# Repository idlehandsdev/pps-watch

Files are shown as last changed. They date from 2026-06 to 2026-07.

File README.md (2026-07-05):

# PPS Watch  

### The Most Accurate Watch that Doesn't Tell Time.

Watch the video (https://youtu.be/AHSqyuOPpf0)

---

## What it does

- Receives GPS , achieves position/time fix
- Outputs 1PPS (one pulse per second) on the GPS module's hardware TIMEPULSE pin, silent until locked, active at 1Hz once locked
- Distributes that PPS signal across a BNC connector via buffered outputs
- Accepts an external PPS reference, compares it against the GPS PPS via a hardware XOR phase comparator, with LED indicators for PPS presence and phase offset
- No microcontroller. No firmware. The GPS module's hardware PPS pin drives the LEDs and BNC outputs directly through logic buffers.

## Hardware

- **GPS module:** u-blox MAX-M10S
- **Antenna:** External via SMA, no onboard antenna. Direct-mount stub antennas (Quectel YEGT001AA right-angle / YEGT002AA straight) screw directly onto the SMA connector, no cable
- **Buffering:** 2x 74HC125 quad buffer (GPS output side, external input side)
- **Comparator:** 74AHC1G86 single XOR gate
- **Indicators:** 0805 SMD LEDs -- 1x red (PPS), 2x green (fix / external PPS)
- **Power:** CR2450 coin cell, switched via SW1, V_BCKP always connected
- **Config port:** Qwiic (I2C) for one-time setup via u-center if needed
- **Connectors:** 2x BNC, 1x SMA (antenna), 1x Qwiic

See the schematic for full signal flow and the BOM for part numbers.

## CAD

This is a KiCad project. PCB mechanical design and 3D assembly were done in Fusion 360.

**Fusion 360 share link:** https://a360.co/4xXmWnG

## BOM

- ** BOM should be up to date! - https://www.digikey.ca/en/mylists/list/XIH163JVIJ
- ** R2 was a 0R resistor, but the BOM now includes a PTC instead.

| Reference | Qty | Value | Digikey Part No. |
|---|---|---|---|
| AE3 | 1 | YEGT002AA | [2958-YEGT002AA-ND](https://www.digikey.com/en/products/detail/quectel/YEGT002AA/17101891) |
| BT2 | 1 | BU2450SM-JJ-G | [BU2450SM-JJ-GCT-ND](https://www.digikey.com/en/products/detail/mpd-memory-protection-devices/BU2450SM-JJ-GTR/3028728) |
| C1 | 1 | 100pF C0G | 311-1111-1-ND |
| C2, C3, C4, C5 | 4 | 0.1uF | 311-4348-1-ND |
| D1 | 1 | LED Red 0805 | 160-1415-1-ND |
| D2 | 1 | PESD0402-140 | [PESD0402-140CT-ND](https://www.digikey.com/en/products/detail/littelfuse-inc/PESD0402-140/1968526) |
| D3, D4 | 2 | LED Green 0805 | [475-LGR971-KN-1TR-ND](https://www.digikey.com/en/products/detail/LG%20R971-KN-1/475-1410-1-ND/1802598) |
| J1, J4 | 2 | BNC 2466267-1 | 17-2466267-1-ND |
| J2 | 1 | CONSMA002-SMD-G-T | 343-CONSMA002-SMD-G-TCT-ND |
| J6 | 1 | Qwiic | 1568-14417-ND |
| L1 | 1 | Ferrite Bead | 490-1040-1-ND |
| R1 | 1 | 470R | 311-470ARCT-ND |
| R2 | 1 | 500mA PolyFuse | F2772CT-ND |
| R3, R6 | 2 | 10K | 311-10KARCT-ND |
| R4, R5 | 2 | 330R | 311-330ARCT-ND |
| SW1 | 1 | Power Switch SPDT | 401-2016-1-ND |
| U1 | 1 | MAX-M10S | 672-MAX-M10S-00BTR-ND |
| U3, U6 | 2 | 74HC125D | [74HC125DCT-ND](https://www.digikey.com/en/products/detail/toshiba-semiconductor-and-storage/74HC125D/6198795) |
| U5 | 1 | 74AHC1G86 | [296-1094-1-ND](https://www.digikey.com/en/products/detail/texas-instruments/SN74AHC1G86DBVR/276738) |

## Watch Assembly

### 3D Printed Parts

Print the following files from the `CAD/` folder:

- `CAD/pcb_frame_mount.stl` -- frame that holds the PCB
- `CAD/watch_band_mount.stl` -- mounts the band to the frame

### Watch Band

Any standard 22mm watch band works. Tested with:

[Bandini Nylon Sports Watch Band Strap 22mm](https://www.amazon.com/dp/B09R2BVRWQ)

### Hardware

- 2 x M2x6mm Flat Head Plastic Threading Screws to mount body to strap mount. - https://www.mcmaster.com/90485A415/
- 2 x M3x6mm Pan Head Plastic Threading Screws for mounting PCB to Body - https://www.mcmaster.com/99461A939/
- 2 x M3x35mm Round Head Machine Screws to mount strap. Just Thread into the plastic snugly https://www.mcmaster.com/92000A134/
---

*Felix Corp -- Idle Hands Dev R&D Division*
*Asset Tag: FC-IDH-UTC-001*

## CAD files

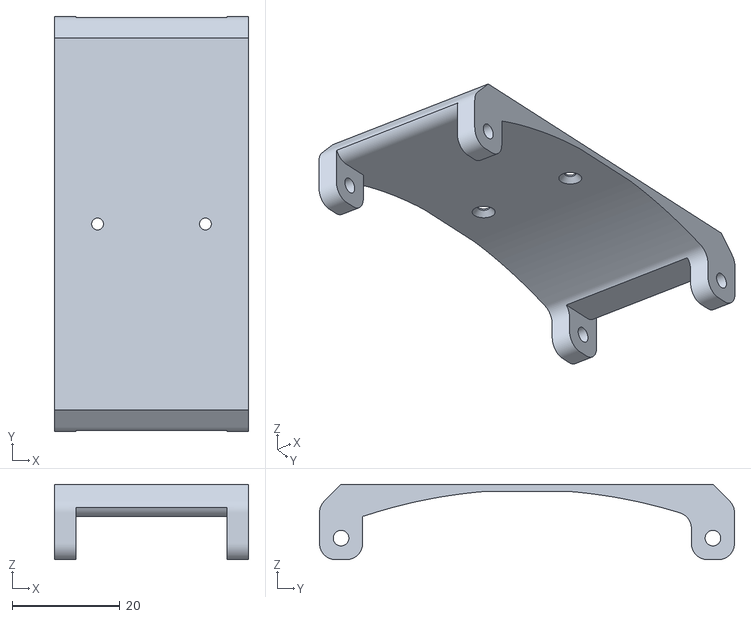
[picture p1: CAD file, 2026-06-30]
CAD/watch_band_mount.stl
36.0 x 77.0 x 14.0

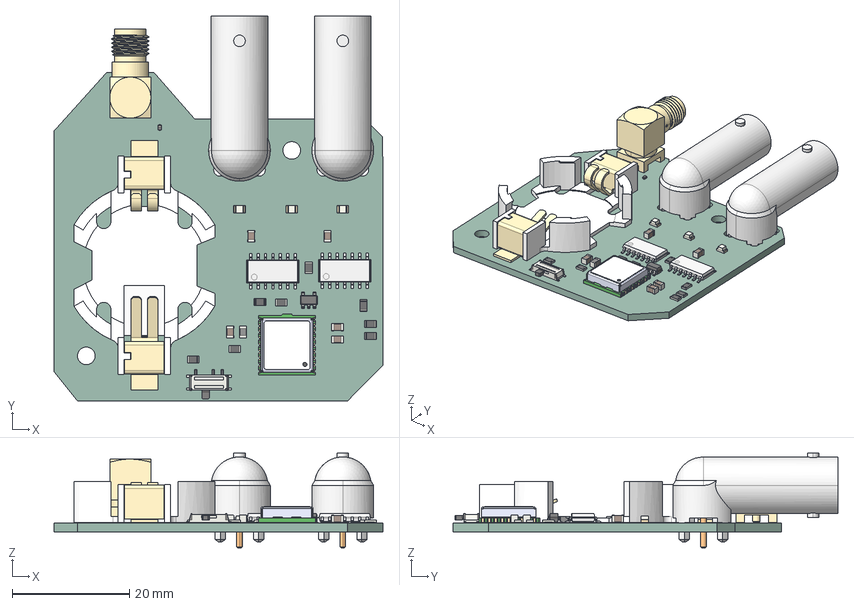
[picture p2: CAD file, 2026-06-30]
kicad/pps_watch.step
56.0 x 65.6 x 16.2 mm
R_0805_2012Metric x 8
BU2450SM-JJ-G
SOT-23-5
Fusion_sp
LED_0805_2012Metric x 3
C_0805_2012Metric x 5
MAX-M10S-00B
CONSMA002-SMD-G
D_SOD_923
L_0805_2012Metric
pps_watch_PCB

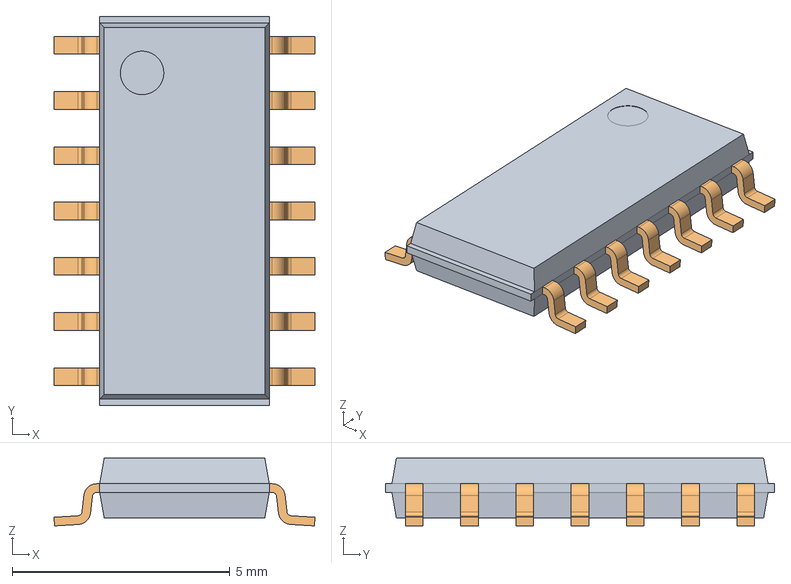
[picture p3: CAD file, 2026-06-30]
kicad/project_libs/3DPackages/SOIC14_z90.stp
6.00 x 8.95 x 1.56 mm

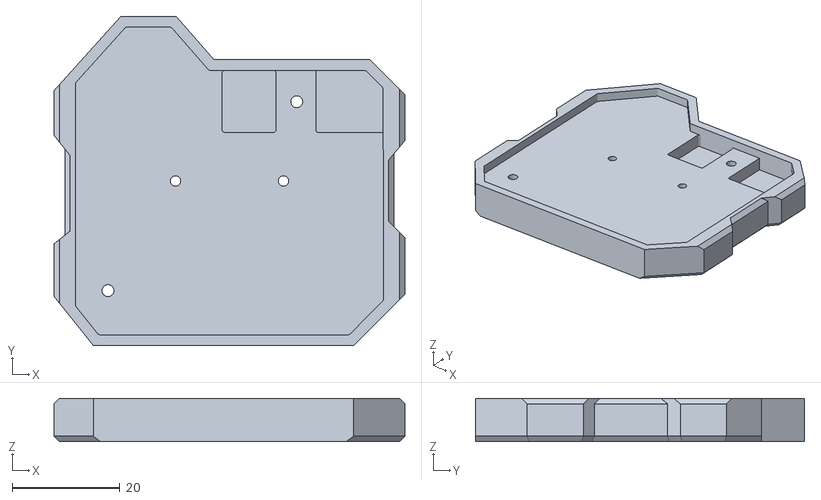
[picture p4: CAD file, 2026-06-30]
CAD/pcb_frame_mount.stl
65.0 x 61.0 x 8.00

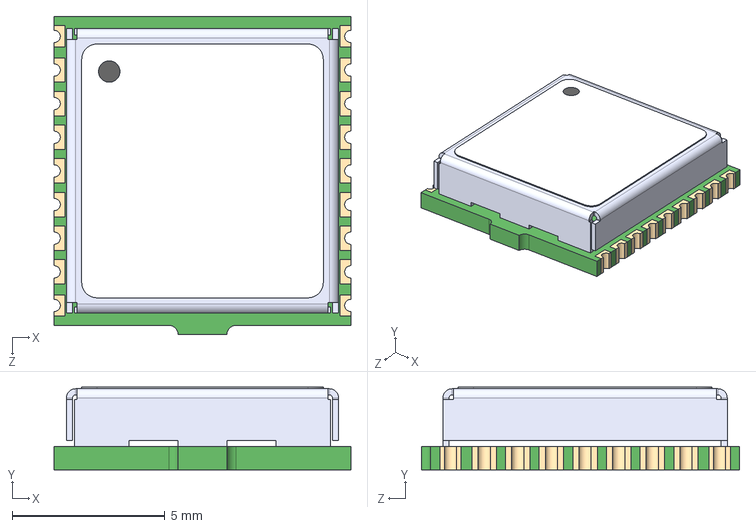
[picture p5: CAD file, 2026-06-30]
kicad/project_libs/3DPackages/MAX-M10S-00B.step
9.70 x 2.70 x 10.4 mm

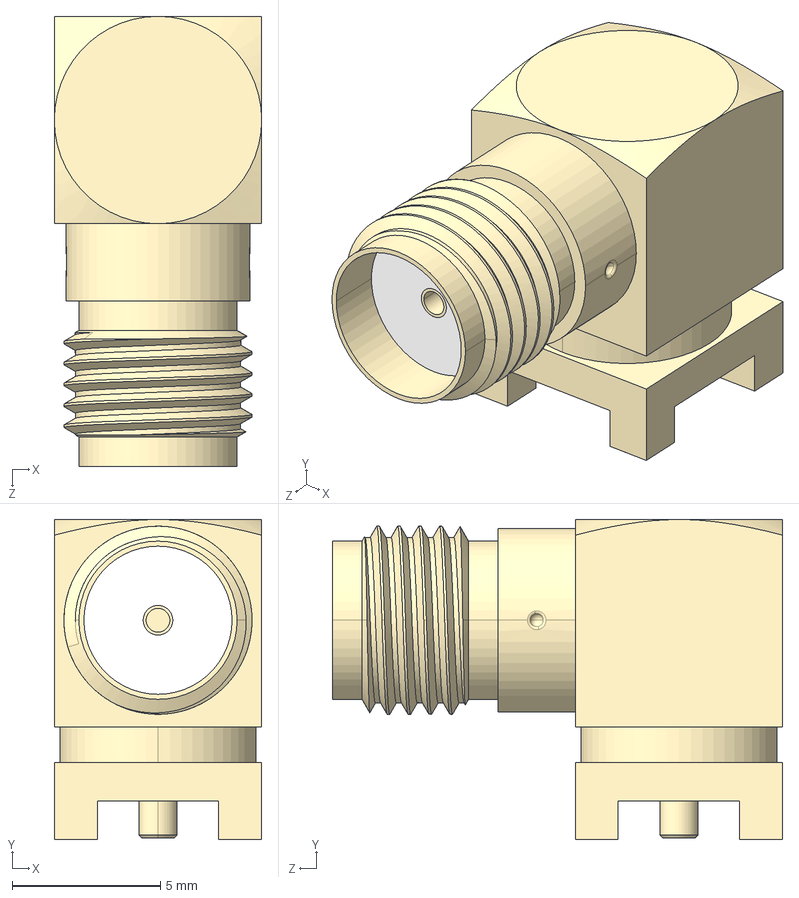
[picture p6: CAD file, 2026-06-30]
kicad/project_libs/3DPackages/CONSMA002-SMD-G-T.step
7.00 x 10.8 x 15.2 mm

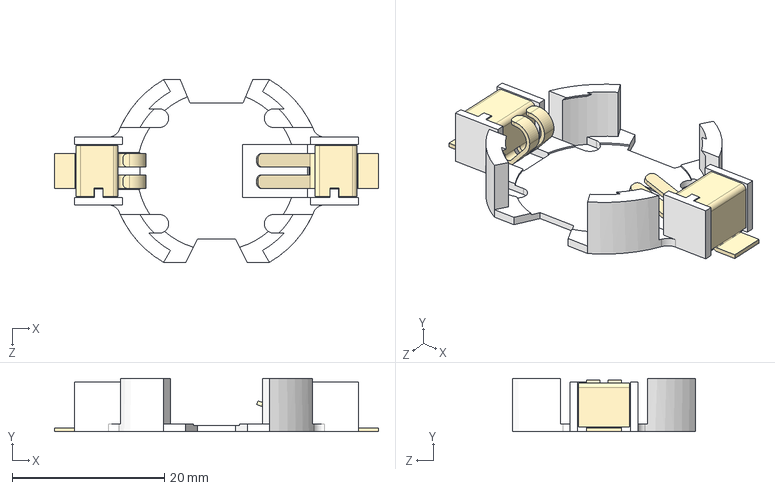
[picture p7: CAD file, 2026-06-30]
kicad/project_libs/3DPackages/BU2450SM-JJ-G.step
42.5 x 7.00 x 24.0 mm

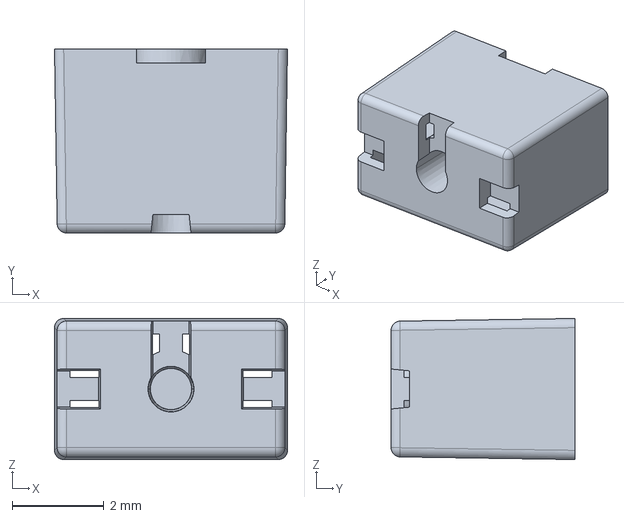
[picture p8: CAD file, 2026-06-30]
kicad/project_libs/3DPackages/1462350001.stp
5.07 x 4.00 x 3.07 mm

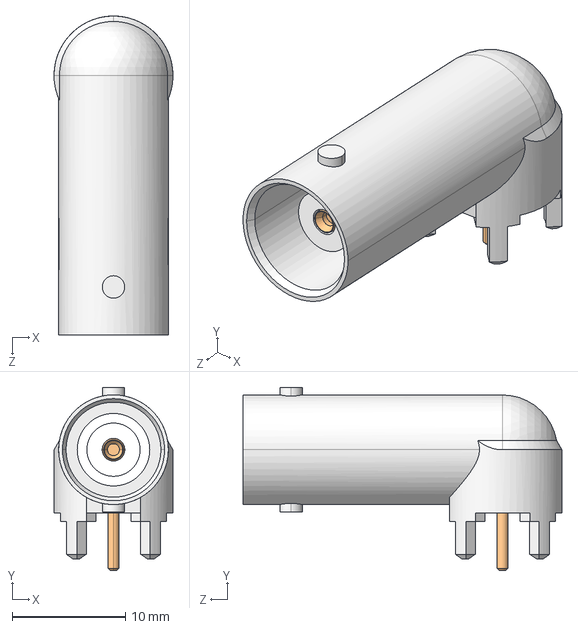
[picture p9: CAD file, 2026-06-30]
kicad/project_libs/3DPackages/2466267-1.step
10.5 x 16.2 x 28.1 mm

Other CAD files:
CAD/watch_frame.f3d

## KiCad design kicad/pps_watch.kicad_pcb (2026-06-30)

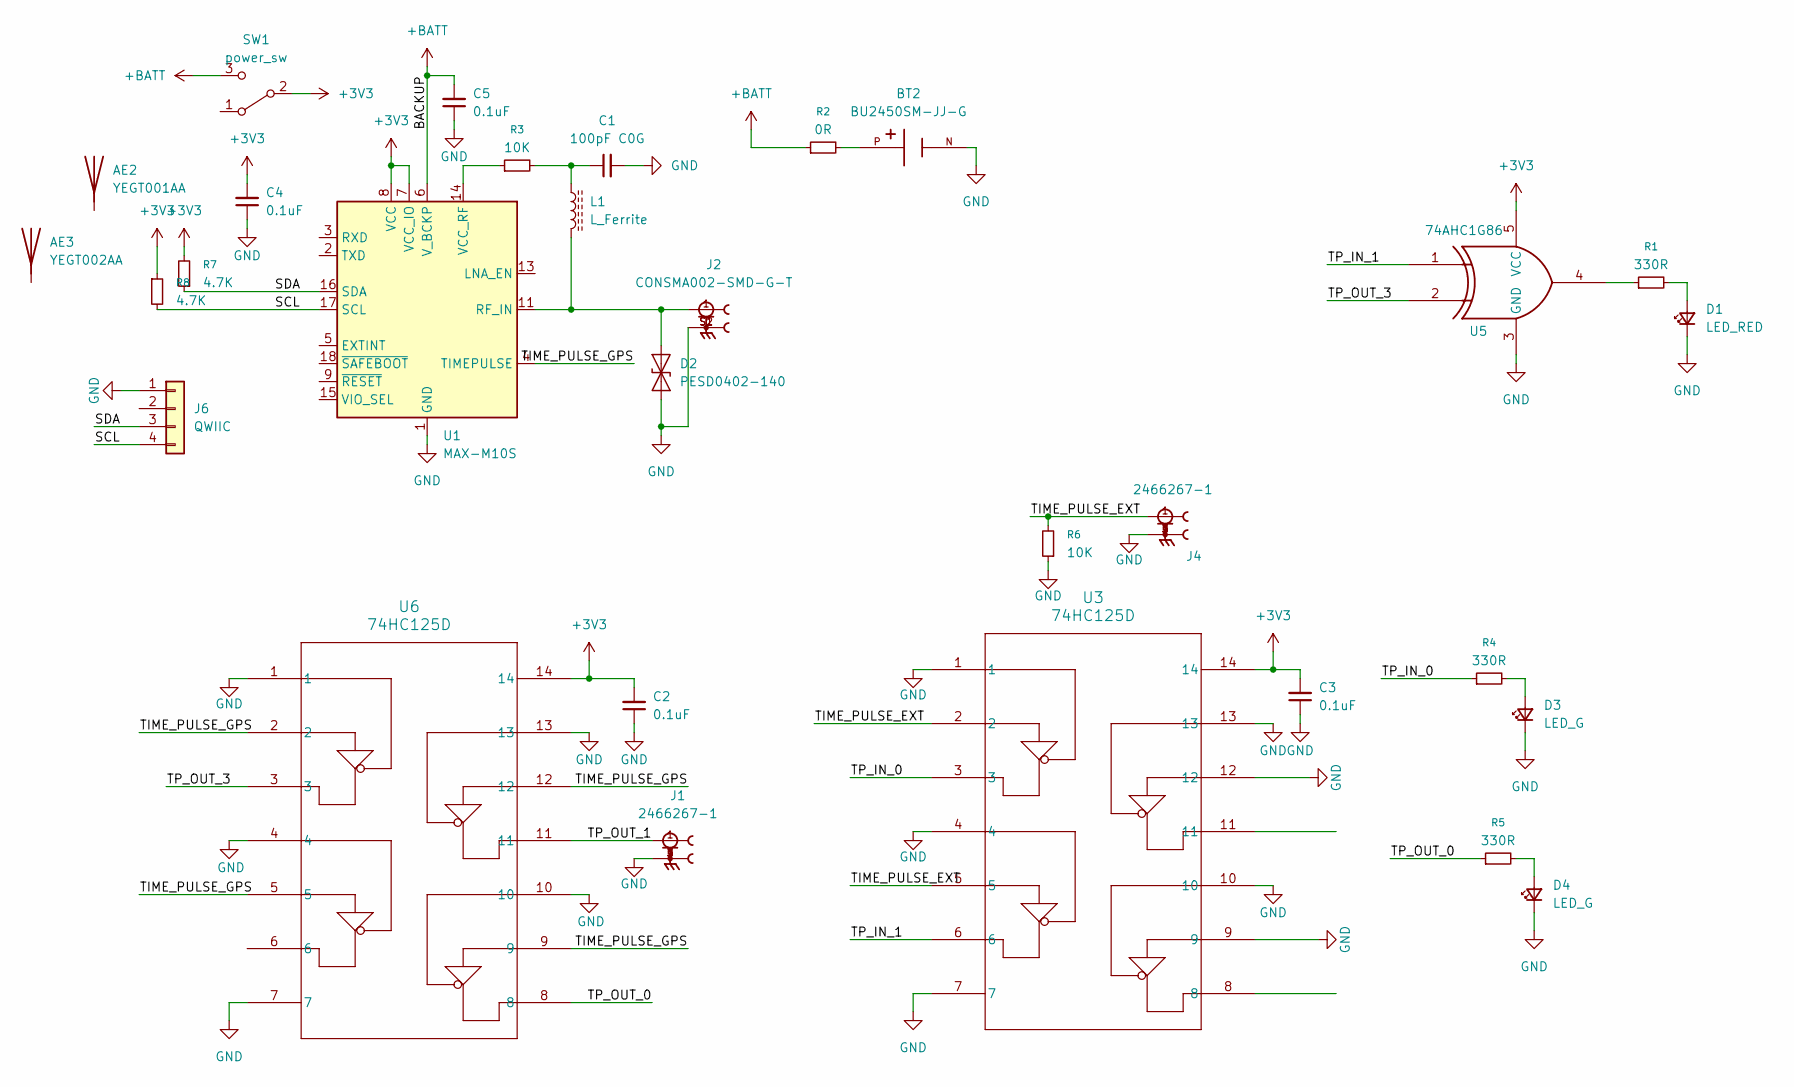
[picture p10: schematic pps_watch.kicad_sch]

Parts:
AE2: YEGT001AA; Digikey Part No. 2958-YEGT001AA-ND
AE3: YEGT002AA; Digikey Part No. 2958-YEGT002AA-ND
BT2: BU2450SM-JJ-G; BAT_BU2450SM-JJ-G; PARTREV J; Digikey Part No. BU2450SM-JJ-GCT-ND
C1: 100pF C0G; C_0805_2012Metric; Digikey Part No. 311-1111-1-ND
C2, C3, C4, C5: 0.1uF; C_0805_2012Metric
D1: LED_RED; LED_0805_2012Metric; Digikey Part No. 160-1415-1-ND
D2: PESD0402-140; D_SOD-923; Digikey Part No. PESD0402-140CT-ND
D3, D4: LED_G; LED_0805_2012Metric; Digikey Part No. 475-LGR971-KN-1TR-ND
J1, J4: 2466267-1; TE_2466267-1; PARTREV A1; Digikey Part No. 17-2466267-1-ND
J2: CONSMA002-SMD-G-T; LINX_CONSMA002-SMD-G-T; Digikey Part No. 343-CONSMA002-SMD-G-TCT-ND
J6: QWIIC; CONN_SM04B-SRSS-TB_JST; Digikey Part No. 1528-4328-ND
L1: L_Ferrite; L_0805_2012Metric; Digikey Part No. 490-1040-1-ND
R1, R4, R5: 330R; R_0805_2012Metric
R2: 0R; R_0805_2012Metric
R3, R6: 10K; R_0805_2012Metric
R7, R8: 4.7K; R_0805_2012Metric
SW1: power_sw; SW_SPDT_PCM12; Digikey Part No. 401-2016-1-ND
U1: MAX-M10S; ublox_MAX; Digikey Part No. 672-MAX-M10S-00BTR-ND
U3, U6: 74HC125D; SOIC14_TOS; Digikey Part No. 74HC125DCT-ND
U5: 74AHC1G86; SOT-23-5; Digikey Part No. 296-1094-1-ND

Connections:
+3V3: C2.2, C3.2, C4.2, R7.2, R8.1, SW1.2 (B), U1.7 (VCC_IO), U1.8 (VCC), U3.14, U5.5 (VCC), U6.14
+BATT: C5.2, R2.1, SW1.3 (C), U1.6 (V_BCKP)
/SCL: J6.4, R8.2, U1.17 (SCL)
/SDA: J6.3, R7.1, U1.16 (SDA)
/TIME_PULSE_EXT: J4.1, R6.2, U3.2, U3.5
/TIME_PULSE_GPS: U1.4 (TIMEPULSE), U6.2, U6.5, U6.9, U6.12
/TP_IN_0: R4.1, U3.3
/TP_IN_1: U3.6, U5.1
/TP_OUT_0: R5.1, U6.8
/TP_OUT_1: J1.1, U6.11
/TP_OUT_3: U5.2, U6.3
GND: BT2.N, C1.2, C2.1, C3.1, C4.1, C5.1, D1.1 (K), D2.1 (A1), D3.1 (K), D4.1 (K), J1.2, J1.3, J1.4, J1.5, J2.S1, J2.S2, J4.2, J4.3, J4.4, J4.5, J6.1, R6.1, U1.1 (GND), U1.10 (GND), U1.12 (GND), U3.1, U3.4, U3.7, U3.9, U3.10, U3.12, U3.13, U5.3 (GND), U6.1, U6.4, U6.7, U6.10, U6.13
unnamed: BT2.P, R2.2
unnamed: C1.1, L1.1, R3.2
unnamed: D1.2 (A), R1.2
unnamed: D2.2 (A2), J2.1, L1.2, U1.11 (RF_IN)
unnamed: D3.2 (A), R4.2
unnamed: D4.2 (A), R5.2
unnamed: R1.1, U5.4
unnamed: R3.1, U1.14 (VCC_RF)

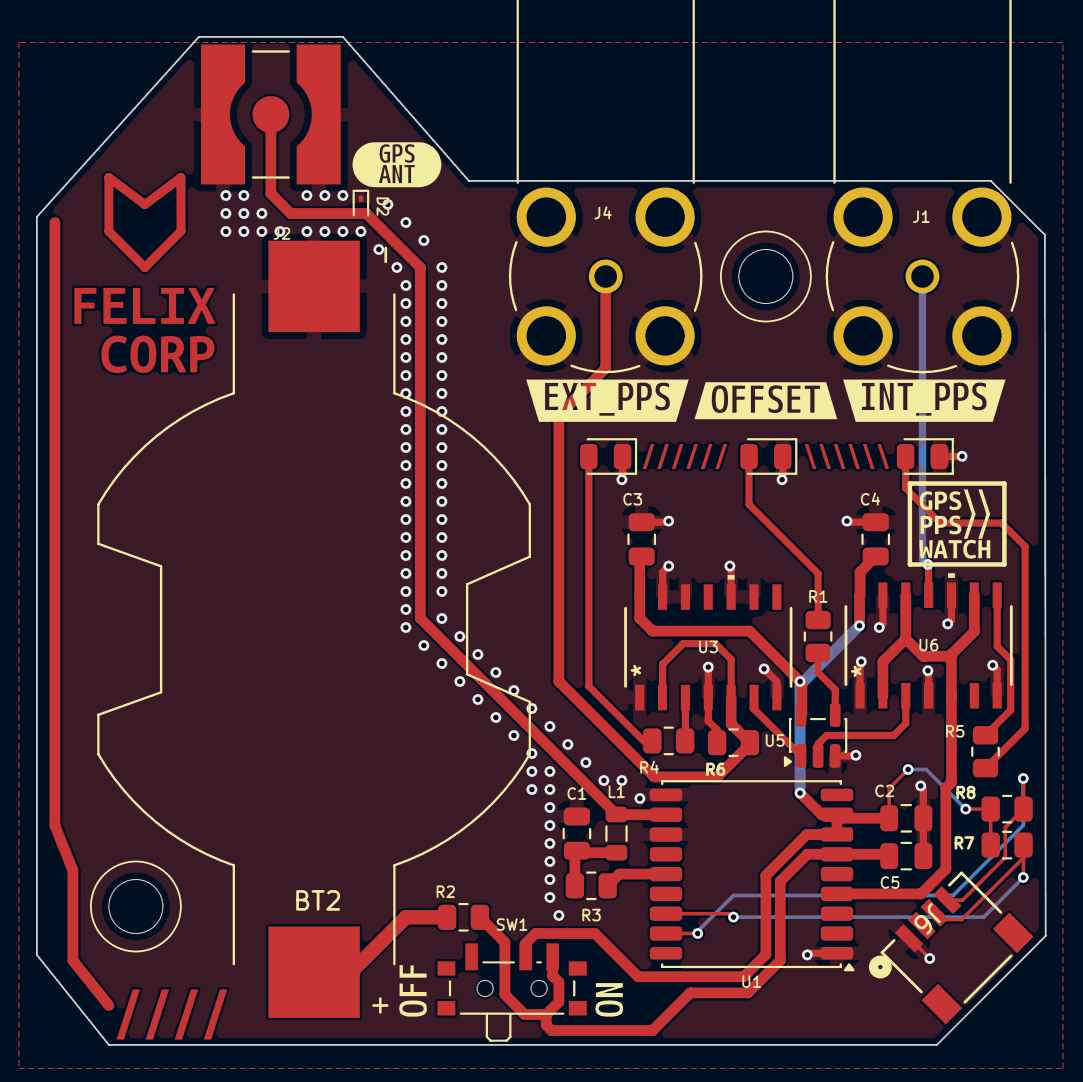
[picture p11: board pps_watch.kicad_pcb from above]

Board: 2 copper layers, 56.0 x 56.0 mm, 39 parts (0 on the bottom side), 20 nets.

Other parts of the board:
kibuzzard-6A225EFE: G***; kibuzzard-6A225EFE
kibuzzard-6A2251CD: G***; kibuzzard-6A2251CD
kibuzzard-6A2254F6: G***; kibuzzard-6A2254F6
kibuzzard-6A2255A9: G***; kibuzzard-6A2255A9
kibuzzard-6A2263B9: G***; kibuzzard-6A2263B9
kibuzzard-6A22543C: G***; kibuzzard-6A22543C
kibuzzard-6A225147: G***; kibuzzard-6A225147
kibuzzard-6A225388: G***; kibuzzard-6A225388
kibuzzard-6A225392: G***; kibuzzard-6A225392
kibuzzard-6A226669: G***; kibuzzard-6A226669
kibuzzard-6A226675: G***; kibuzzard-6A226675

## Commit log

2026-07-03 changed some things, added 3d Print info
2026-07-03 updated BOM to include missing parts
    [pps_watch.kicad_sch]
2026-07-03 updated some info, added BOM table
